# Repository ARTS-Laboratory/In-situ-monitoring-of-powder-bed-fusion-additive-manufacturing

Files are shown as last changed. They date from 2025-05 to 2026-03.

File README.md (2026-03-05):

# In situ monitoring of powder bed fusion additive manufacturing
Hardware and software designs for in situ systems for laser-based powder bed fusion additive manufacturing.

<p align="center">
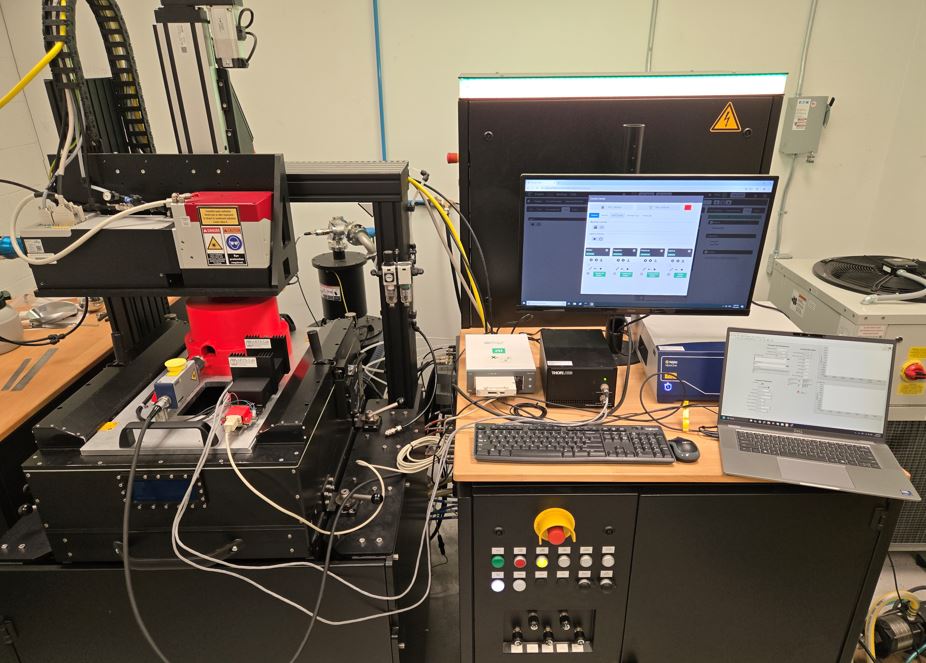
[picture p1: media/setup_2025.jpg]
 <br> 
The laser vibrometer setup of in situ systems for laser-based powder bed fusion additive manufacturing.  
</p>

<p align="center">
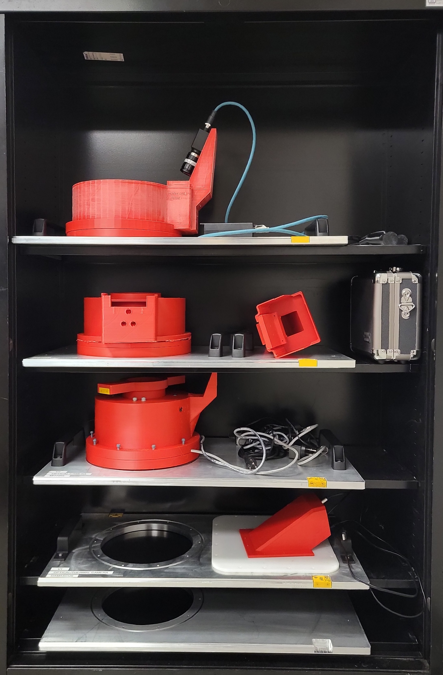
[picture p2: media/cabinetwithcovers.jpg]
 <br> 
Cabinet displaying up to date versions of assembled covers. The following covers in a top-to-bottom arrangement: Uru, Adamant, Mithril, and Damascus. 
</p>

## [System Development](system_development)
The system (hardware and software) design for the project.

## [Aconity MIDI – 3D Reference Models](Aconity_MIDI–3D_Reference_Models)
Simple CAD models for the Aconity MIDI printer used for visualization purposes.

## Licensing and Citation

This work is licensed under a Creative Commons Attribution-ShareAlike 4.0 International License [cc-by-sa 4.0].



#### Bibtex

@Misc{ARTSLabSituMonitoringPowder,  
  author = {{ARTS-L}ab},  
  title  = {In situ monitoring of powder bed fusion additive manufacturing},  
  groups = {{ARTS-L}ab},  
  note = {Accessed: 20xx-xx-xx},  
  url    = {https://github.com/ARTS-Laboratory/In-situ-monitoring-of-Powder-bed-fusion-additive-manufacturing},  
}  

<p align="center">

</p>
<p align="center">
QR code for repo.
</p>

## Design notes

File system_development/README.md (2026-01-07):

# Systems Variations  
Different system variations (i.e., product lines) are named after mythical materials. 

## [Mithril](Mithril)
* A legendary, lightweight, and strong metal from Tolkien’s Middle-earth.
* Sensing system designed with an optical camera.

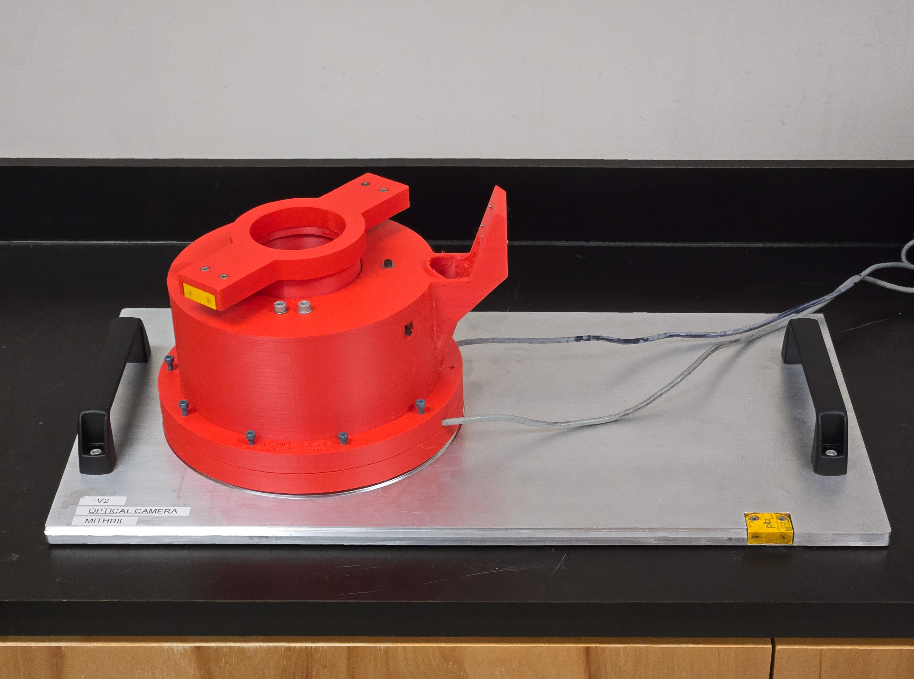
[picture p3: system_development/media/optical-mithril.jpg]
 <br> 
Custom cover with an integrated optical camera mount for laser-based powder bed fusion additive manufacturing monitoring. Camera not yet installed.
</p>

## [Adamant](Adamant)
* An ancient term for an unbreakable, diamond-like substance.
* Sensing system designed with a THERMAL CAMERA.

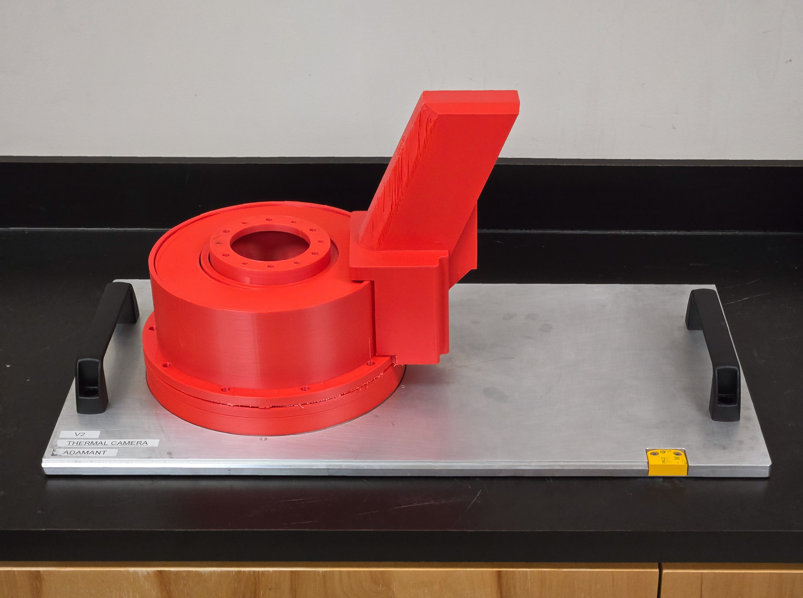
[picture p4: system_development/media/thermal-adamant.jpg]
 <br> 
Custom cover with an integrated thermal camera mount for laser-based powder bed fusion additive manufacturing monitoring. 
</p>

## [Uru](Uru)
* A mystical Asgardian metal, known for its magical properties.
* Sensing system designed with an EVENT CAMERA.

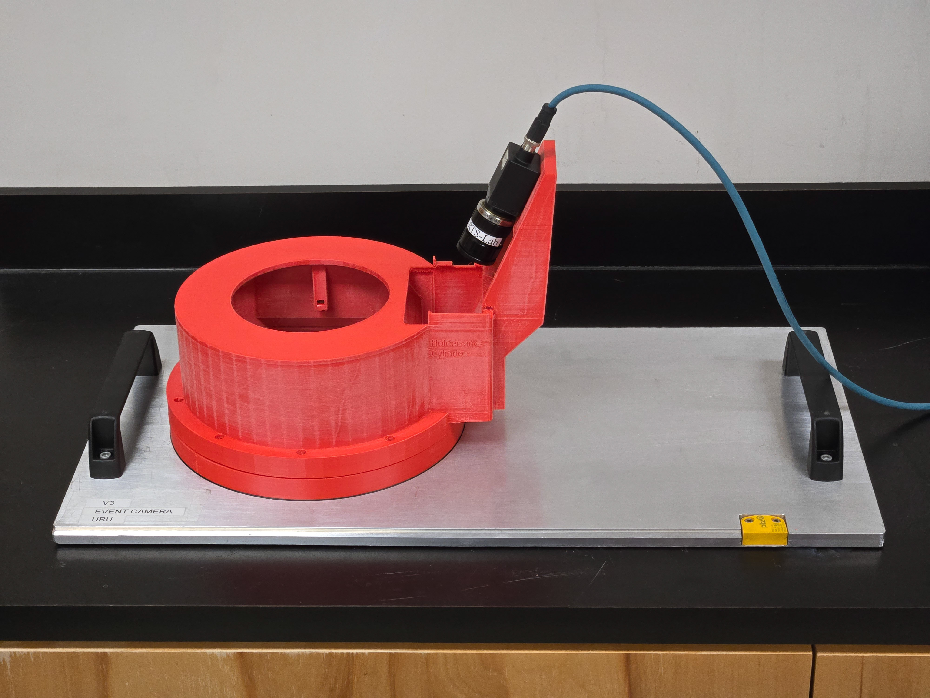
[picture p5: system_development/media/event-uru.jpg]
 <br> 
Custom cover with event camera mount for in-situ monitoring of laser-based powder bed fusion processes.
</p>

## [Orichalcum](Orichalcum)
* A lost golden-red metal from Atlantis and Greek mythology.
* Sensing system designed with a LASER VIBROMETER.

 <br> 
Experimental setup including custom cover assembly, laser vibrometer, piezoelectric transducer, and pulser. 
</p>

## [Damascus](Damascus)
* A famed patterned steel, known for strength and sharpness.
* Sensing system designed with multiple sensing systems.

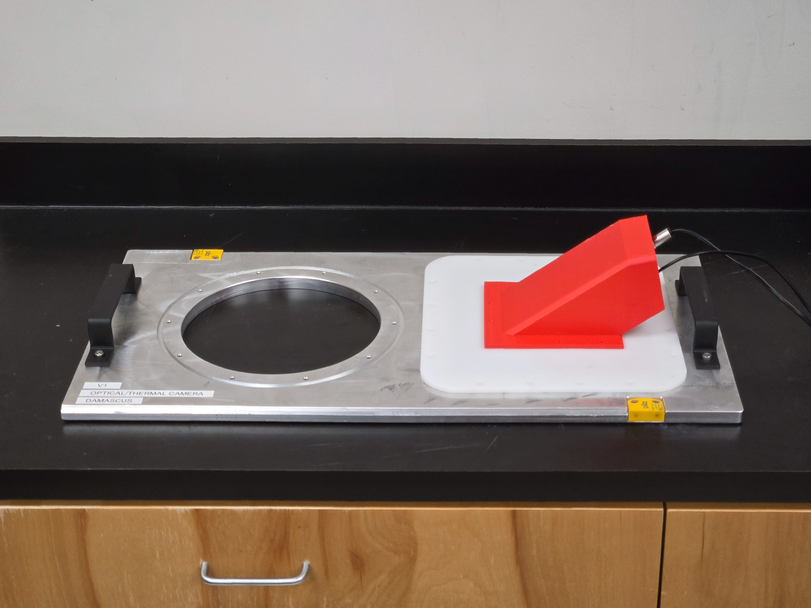
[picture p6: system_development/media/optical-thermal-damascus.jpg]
 <br> 
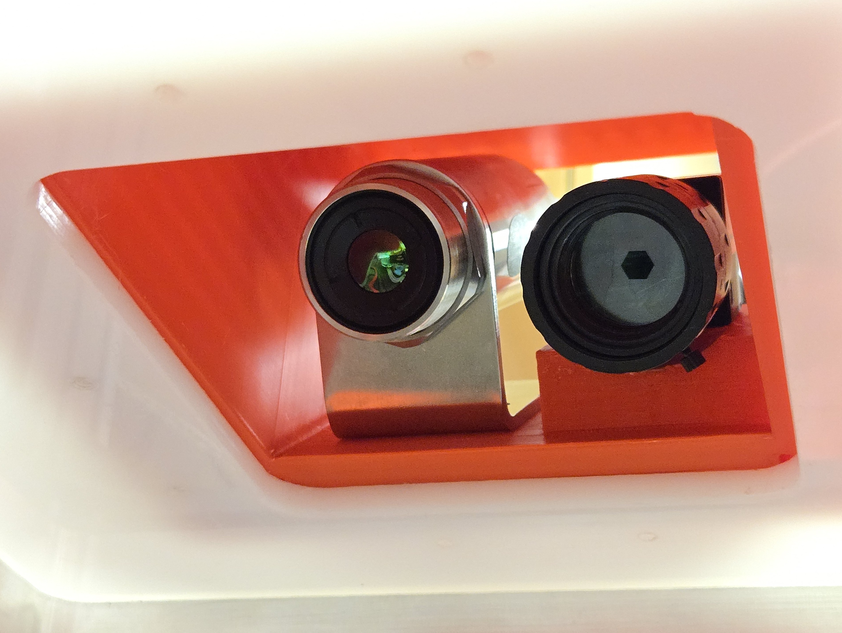
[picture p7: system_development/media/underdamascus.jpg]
 <br> 
Integrated dual vision holder securely mounts a thermal camera and an optical camera for synchronized data acquisition on a custom cover. 
</p>

## [Oblivium](Oblivium)
* A mythical dark metal associated with secrecy, resilience, and hidden power.
* Sensing system designed with EDGE COMPUTING CAPABILITIES for in-situ data processing.
  
 <br> 
 <br> 
Integrated edge computing hardware with an optical camera setup for synchronized data acquisition and processing on a custom cover. 
</p>

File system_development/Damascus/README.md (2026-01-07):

# Damascus
Sensing system designed with multiple sensing systems.

## V0.1
Dual vision holder designed for thermal and optical cameras 
## V0.2
Dual vision holder designed for optical and event cameras 
## V0.3
Triple vision holder desinged for optical, thermal, and event cameras 
To-Do 
    - Expand plate to cover entire hole without spacer
    - Use M6 bolts to mount lid

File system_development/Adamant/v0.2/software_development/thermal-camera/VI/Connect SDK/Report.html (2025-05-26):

Import Shared Library Report

Friday, May 16, 2025 3:06:13 PM

Your generated files are installed in the following folder:
C:\Users\mayhe\OneDrive\Documents\GitHub\In-situ-monitoring-of-powder-bed-fusion-additive-manufacturing\system_development\Orichalcum\v0.2\Software_design\thermal-camera\VI\Connect SDK

Parsing header file warnings:
No errors/warnings occurred when parsing the header file.

The following errors/warnings occurred when generating the wrapper VIs for this shared library.

Cannot create VI
The following VI cannot be created. This might indicate that the associated function contains parameters of a data type that cannot be converted directly. To work around this issue, you can create a custom control or typedef control to represent a complex structure or multidimensional array, then re-run the Import Shared Library wizard and select Update VIs from a shared library. Using the same shared library, step through the wizard again. On the Configure VIs and Controls page, assign the custom control or typedef to the associated parameter(s). Complex structures include nested structures, structures containing arrays, arrays of strings, and multidimensional arrays.
Get Fixed Emissivity.vi
Init Imager IPC.vi
Release Imager IPC.vi
Run Imager IPC.vi
Set Fixed Emissivity.vi
Set Imager IPC Count.vi

VI Not Executable
The VI is not executable because of one of the following reasons:
1. The shared library or a dependent file is not installed. To make the VI executable, you must install the shared library and all support files on the computer on which you run the VI.
2. A required custom control might be empty or cannot be found. To make the VI executable, update the custom control manually.
3. The VI contains a parameter with an unsupported data type. To make the VI executable, you must replace the empty cluster that the wizard generates with a control or indicator that uses supported data types.
Set Callback On Areas Init.vi
Set Callback On Config Changed.vi
Set Callback On Frame Init.vi
Set Callback On Init Completed.vi
Set Callback On LS Slit Center Line.vi
Set Callback On New Frame.vi
Set Callback On New Visible Frame.vi
Set Callback On Play Metadata.vi
Set Callback On Server Stopped.vi
Set Callback On Visible Frame Init.vi

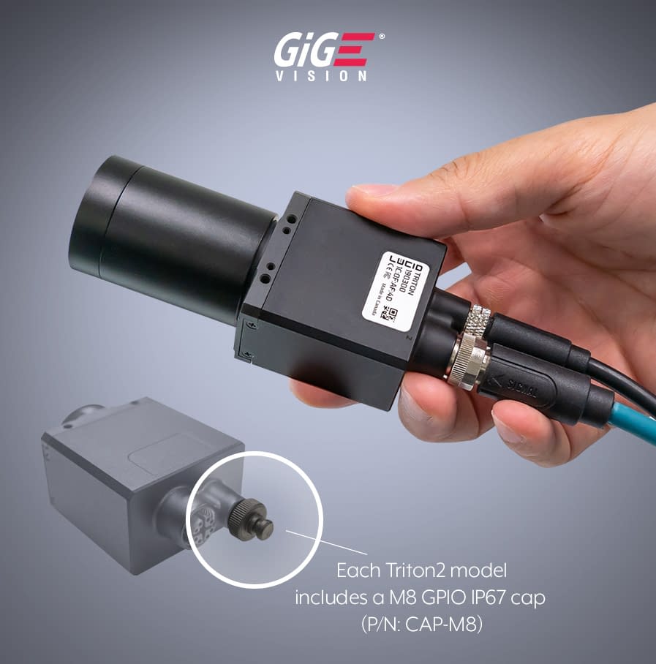
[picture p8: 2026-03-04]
system_development/Uru/Triton2 EVS 0.3MP (IMX637) - EventCamera_files/Triton2-camera-hand-IP67.jpg

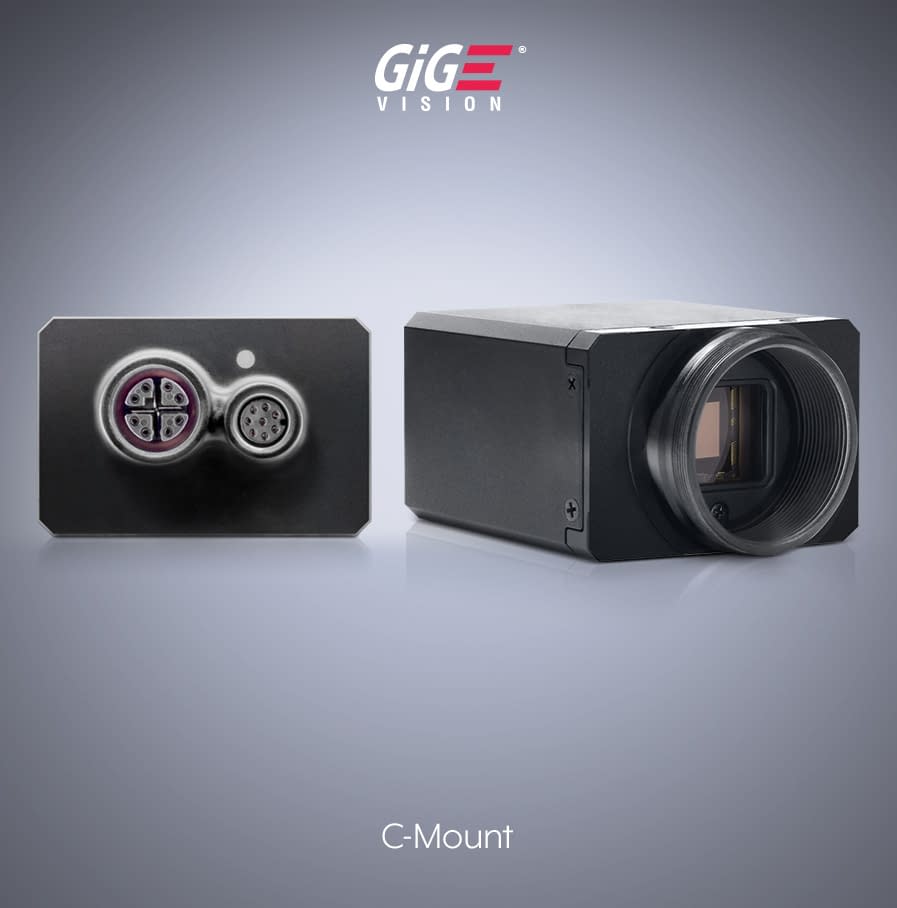
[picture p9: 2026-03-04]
system_development/Uru/Triton2 EVS 0.3MP (IMX637) - EventCamera_files/Triton2-2.5GigE-back-side.jpg

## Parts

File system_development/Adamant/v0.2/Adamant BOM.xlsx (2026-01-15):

Name | Quantity | Source
Aluminum Cover | 1 | Xometry + model
Pull Handle | 2 | https://www.grainger.com/product/JW-WINCO-Pull-Handle-Unthreaded-Holes-813RC8
Horsehoe | 1 | Xometry + model
Head Plate (metal) | 1 | Xometry + model
Welding glass | 1 | Laser Vision (https://lasersafety.com/product/p5p10-window/) | Glass1 (https://www.mscdirect.com/product/details/62674445) | Glass2 (https://www.mscdirect.com/product/details/62674403) | Glass3 (https://www.mscdirect.com/product/details/62674437) | Glass4 (https://www.mscdirect.com/product/details/62674411)
Xi 400 20mm | 1 | optris
Seal Glass Ring | 1 | 3D Printed
Cylinder Housing | 1 | 3D Printed
Camera Lid | 1 | 3D Printed
Cylinder Segment Inner | 1 | 3D Printed
Cylinder Segment Outer | 1 | 3D Printed
Magnet Sensors | 4 | Aconity
M6x15 | 2
M6x20 | 5
M6 ID 11.8mm OD Washer | 7
M6 Nut | 3
M5x40 | 12
M5x20 | 1
M5 ID 9.8mm OD Washer | 16
M5 Nut | 4
M4x14 | 11
M4 ID 8.8mm OD Washer | 11
Rubber Seal (100ft) | 1 | https://www.grainger.com/product/Rubber-Cord-Buna-N-848F88

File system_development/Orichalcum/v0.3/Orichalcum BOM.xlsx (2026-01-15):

Name | Quantity | Source
Aluminum Cover | 1 | Xometry + model
Pull Handle | 2 | https://www.grainger.com/product/JW-WINCO-Pull-Handle-Unthreaded-Holes-813RC8
Head Plate (metal) | 1 | Xometry + model
Seal Glass Ring | 1 | 3D Printed
Cylinder Housing Base | 1 | 3D Printed
Cylinder Housing Cap | 1 | 3D Printed
GV Mount Plate | 1 | 3D Printed
LV Bracket | 1 | 3D Printed
Center Cylinder | 1 | 3D Printed
Magnet Sensors | 4 | Aconity
70mm 8020 Beam | 1
485mm 8020 Beam | 1
M5 x 10 Pan Head | 2
8020 T Nut | 2
M6x20 Set Screw | 2
M6x12 | 2
M6x20 | 4
M6 ID 11.8mm OD Washer | 4
M5x40 | 8
M5x15 | 1
M5 ID 9.8mm OD Washer | 8
M4x14 | 11
M4 ID 8.8mm OD Washer | 11
Rubber Seal (100ft) | 1 | https://www.grainger.com/product/Rubber-Cord-Buna-N-848F88

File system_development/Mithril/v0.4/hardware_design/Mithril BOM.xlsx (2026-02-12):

Name | Quantity | Source
Aluminum Cover | 1 | Xometry + model
Pull Handle | 2 | https://www.grainger.com/product/JW-WINCO-Pull-Handle-Unthreaded-Holes-813RC8
Head Plate (metal) | 1 | Xometry + model
FLIR Blackfly Camera | 1
Edmunds Optis 25mm Lens | 1
Seal Glass Ring | 1 | 3D Printed
Cylinder Housing | 1 | 3D Printed
Camera Lid | 1 | 3D Printed
Cylinder Segment Inner | 1 | 3D Printed
Cylinder Segment Outer | 1 | 3D Printed
Magnet Sensors | 4 | Aconity
M6x15 Bolt | 2
M6x20 Bolt | 4
M6 ID 11.8mm OD Washer | 6
M6 Nut | 2
M5x40 Bolt | 12
M5 ID 9.8mm OD Washer | 15
M4x14 Bolt | 11
M4 ID 8.8mm OD Washer | 11
M3x25 Bolt | 3
M3x10 Pan Head Bolt | 4
M3 Washer | 4
M3 Nuts | 4
Rubber Seal (100ft) | 1 | https://www.grainger.com/product/Rubber-Cord-Buna-N-848F88

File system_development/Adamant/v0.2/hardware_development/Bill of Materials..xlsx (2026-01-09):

Name | Quantity | Source 1 | Source 2 | Source 3
Cover | 1 | Xometry + model
300mm Housing 1 | 1 | 3D Printed
300mm Housing 2 | 1 | 3D Printed
Cylinder Spacer | 1 | 3D Printed
Cylinder Segment Inner | 1 | 3D Printed
Cylinder Segment Outer | 1 | 3D Printed
Cylinder Segment 1 | 1 | 3D Printed
Cylinder Segment Face | 1 | 3D Printed
Camera Bracket | 1 | 3D Printed
Flir Camera Blackfly | 1 | Teledyne Flir Blackfly S USB3 1.6MP Color Camera BFS-U3-16S2C-CS (https://www.bhphotovideo.com/c/product/1844599-REG/teledyne_flir_bfs_u3_16s2c_cs_blackfly_s_usb3_1_6mp.html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)
Welding glass | 1 | Laser Vision (https://lasersafety.com/product/p5p10-window/) | Glass1 (https://www.mscdirect.com/product/details/62674445) | Glass2 (https://www.mscdirect.com/product/details/62674403) | Glass3 (https://www.mscdirect.com/product/details/62674437) | Glass4 (https://www.mscdirect.com/product/details/62674411)
Cover ^ 2 | 1 | 3D Printed
Cover ^ 3 | 1 | 3D Printed
Cylinder Segment Holder | 1 | 3D Printed
Head Plate (metal) | 1 | Xometry + model
M6 x 10 | 4 | M6-1 Thread Size, 10 mm Lg, Socket Head Cap Screw - 26LG36|M07000.060.0010 - Grainger (https://www.grainger.com/product/Socket-Head-Cap-Screw-M6-1-26LG36)
M4 x 14 | 2 | M4-0.7 Thread Size, 14 mm Lg, Socket Head Cap Screw - 4XY51|SC2204014-100P - Grainger (https://www.grainger.com/product/Socket-Head-Cap-Screw-M4-0-4XY51)
M5 x 20 | 10 | https://www.grainger.com/product/Socket-Head-Cap-Screw-M5-0-26LG28
M5 x 50 | 9 | M5-0.8 Thread Size, 50 mm Lg, Socket Head Cap Screw - 6CE82|M07000.050.0050 - Grainger (https://www.grainger.com/product/Socket-Head-Cap-Screw-M5-0-6CE82)
M5 x 16 | 10 | M5-0.8 Thread Size, 16 mm Lg, Socket Head Cap Screw - 23NN83|M51050.050.0016 - Grainger (https://www.grainger.com/product/Socket-Head-Cap-Screw-M5-0-23NN83)
M4 x 12 | 14 | https://www.grainger.com/product/Socket-Head-Cap-Screw-M4-0-22UC39
M3 x 16 | 2 | https://www.grainger.com/product/Socket-Head-Cap-Screw-M3-0-22TZ13
M3 x 8 | 3 | https://www.grainger.com/product/Socket-Head-Cap-Screw-M3-0-22TY48
M3 x 35 | 2 | https://www.grainger.com/product/Socket-Head-Cap-Screw-M3-0-22UC31
M3 x 25 | 1 | https://www.grainger.com/product/Socket-Head-Cap-Screw-M3-0-22UC28
M5 nut | 21 | https://www.grainger.com/product/Hex-Nut-M5-0-80-Thread-22YK31
M3 nut | 3 | https://www.grainger.com/product/Hex-Nut-M3-0-50-Thread-6CA29
M4 nut | 2 | https://www.grainger.com/product/Hex-Nut-M4-0-70-Thread-22UK82
Pull Handle | 2 | https://www.grainger.com/product/JW-WINCO-Pull-Handle-Unthreaded-Holes-813RC8
Rubber Seal | 1 | https://www.grainger.com/product/Buna-N-Round-Cord-Buna-N-6RTT7

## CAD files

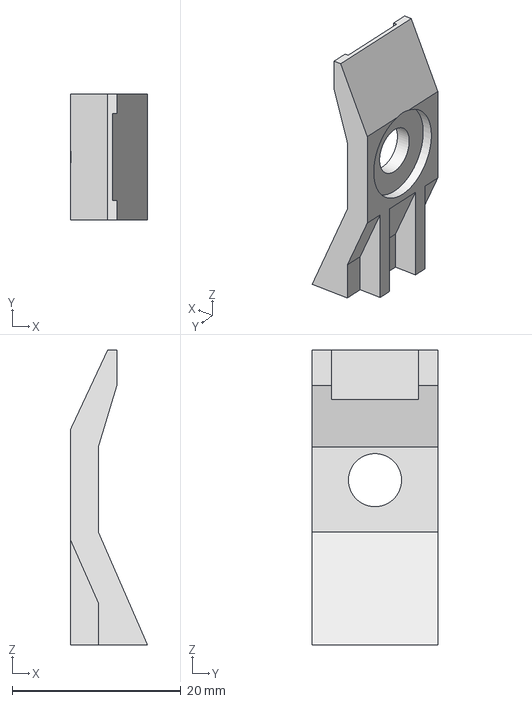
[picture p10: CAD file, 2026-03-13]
accessories/Battery Holder/STEP files/CLAMP.stp
9.15 x 15.0 x 35.0 mm

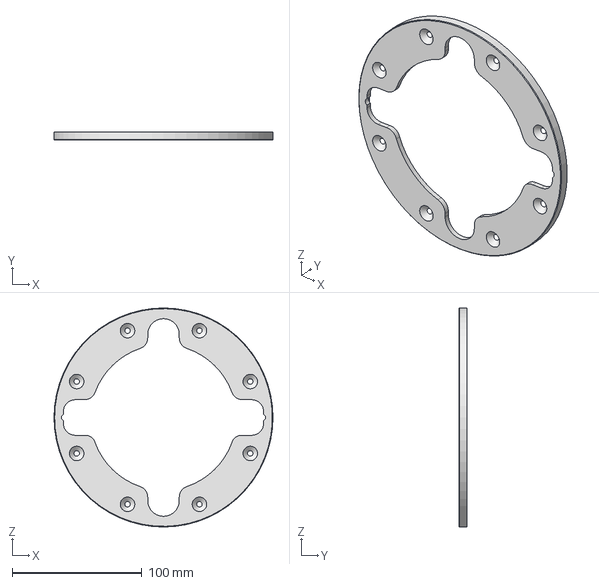
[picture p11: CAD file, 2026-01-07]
accessories/Build platform/Clamp Ring.stp
169.0 x 6.50 x 169.0 mm

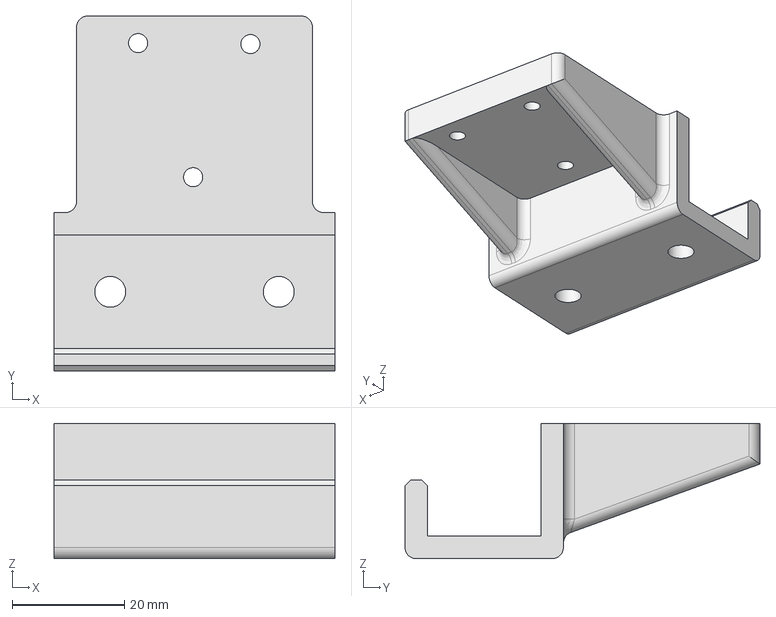
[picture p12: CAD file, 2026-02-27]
accessories/Camera Beam Mount/Optical Camera 8020 Bracket.stp
50.0 x 63.2 x 24.1 mm

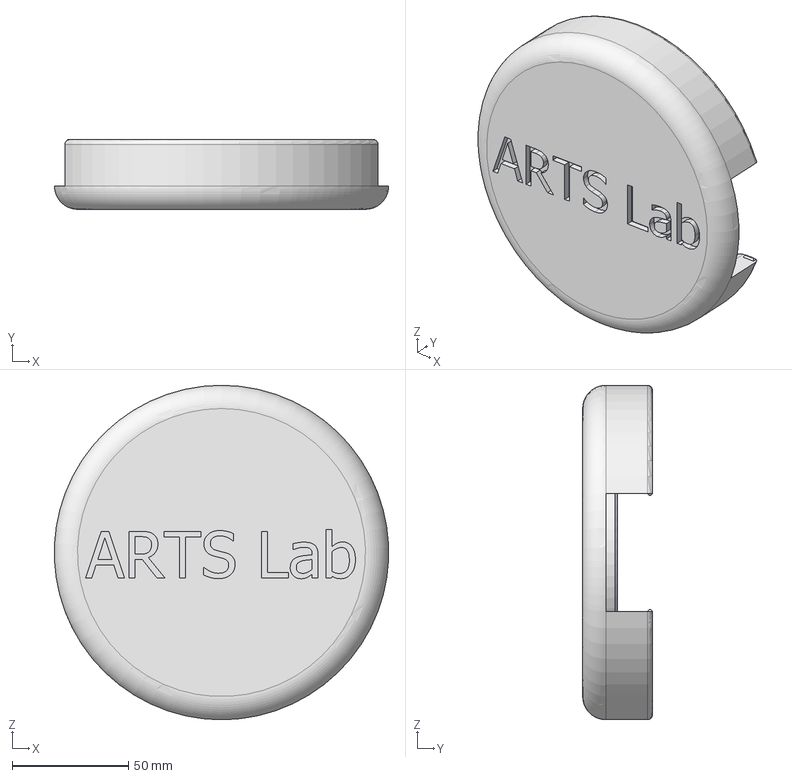
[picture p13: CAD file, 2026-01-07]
accessories/Head plate cover/STEP/Access Cap.stp
143.8 x 30.0 x 144.0 mm

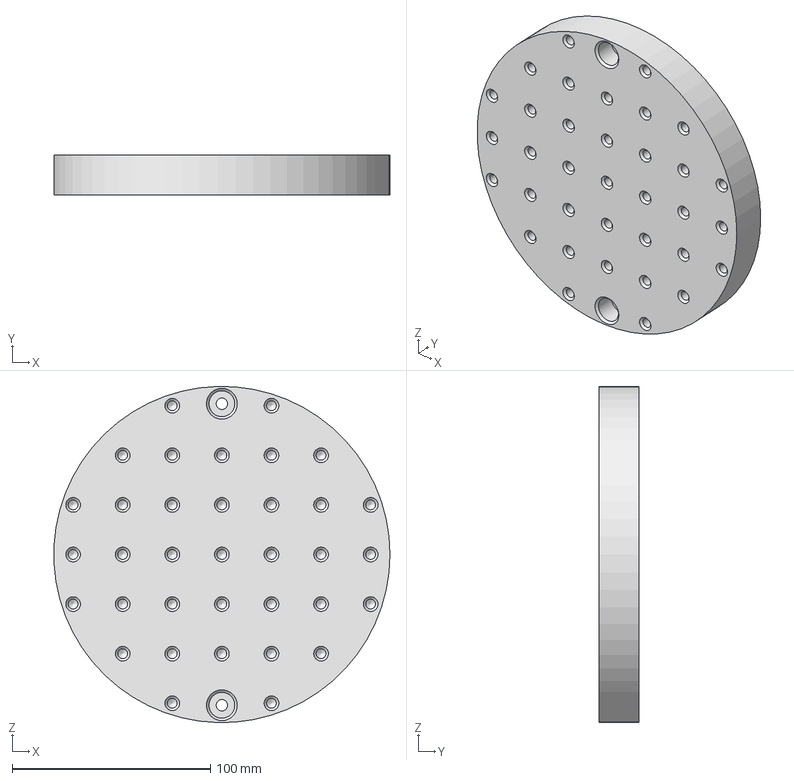
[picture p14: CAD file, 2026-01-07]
accessories/threaded_build-plate/substrate plate With Lots of holes.stp
169.4 x 20.0 x 169.4 mm

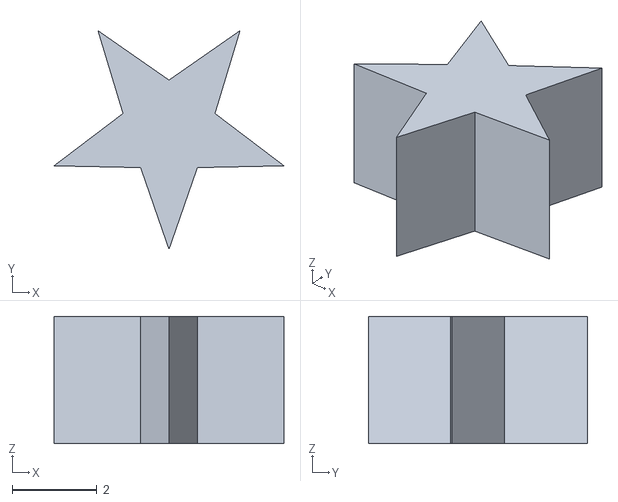
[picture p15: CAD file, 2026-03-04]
system_development/Adamant/v0.2/hardware_development/STEP Files/shape-star-5-points.stl
5.42 x 5.16 x 3.00

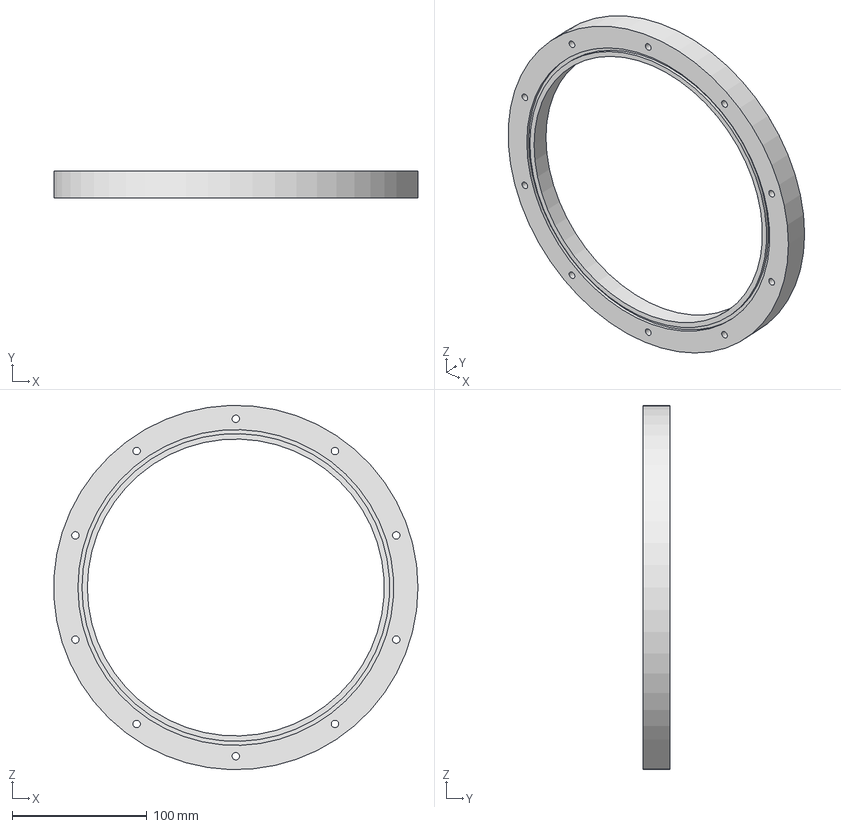
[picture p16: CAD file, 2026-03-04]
system_development/Mithril/v0.4/hardware_design/STEP Files/SealedGlassRing12-16-25.stp
269.7 x 20.0 x 269.9 mm

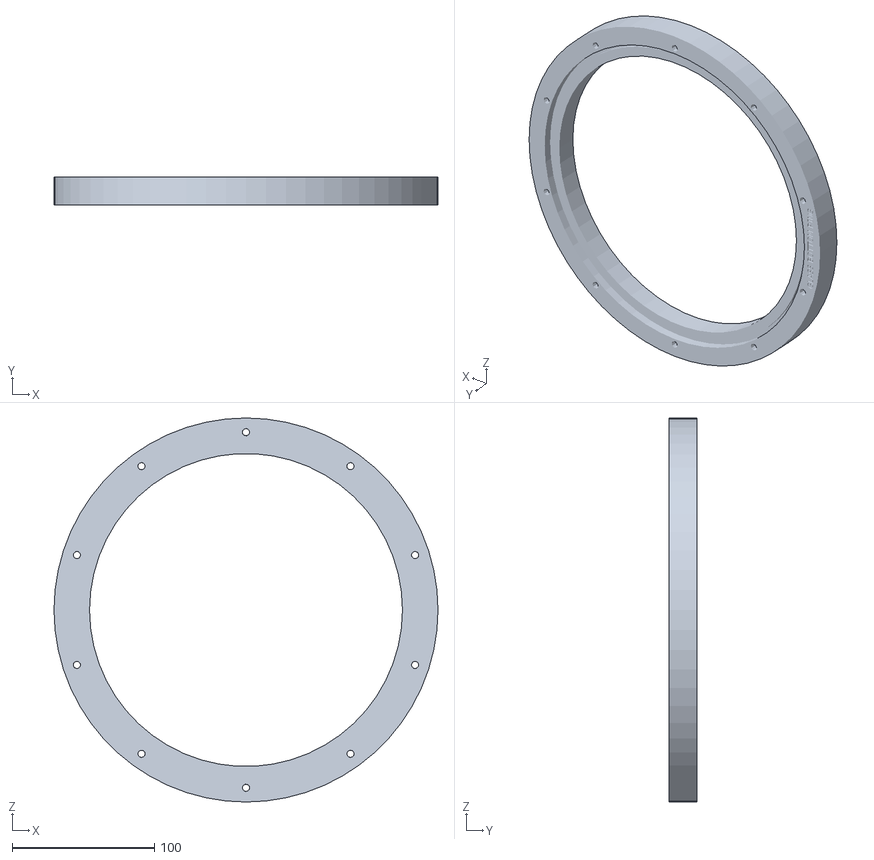
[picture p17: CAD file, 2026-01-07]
system_development/Orichalcum/v0.3/GlassBottomRing.stl
270.0 x 20.0 x 270.0

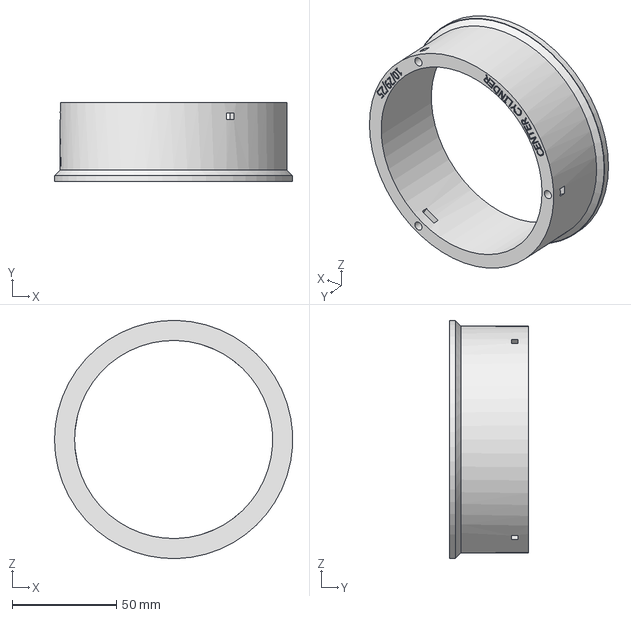
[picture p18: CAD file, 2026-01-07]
system_development/Orichalcum/v0.3/step files/CenterCylinder.stp
114.3 x 38.0 x 114.3 mm

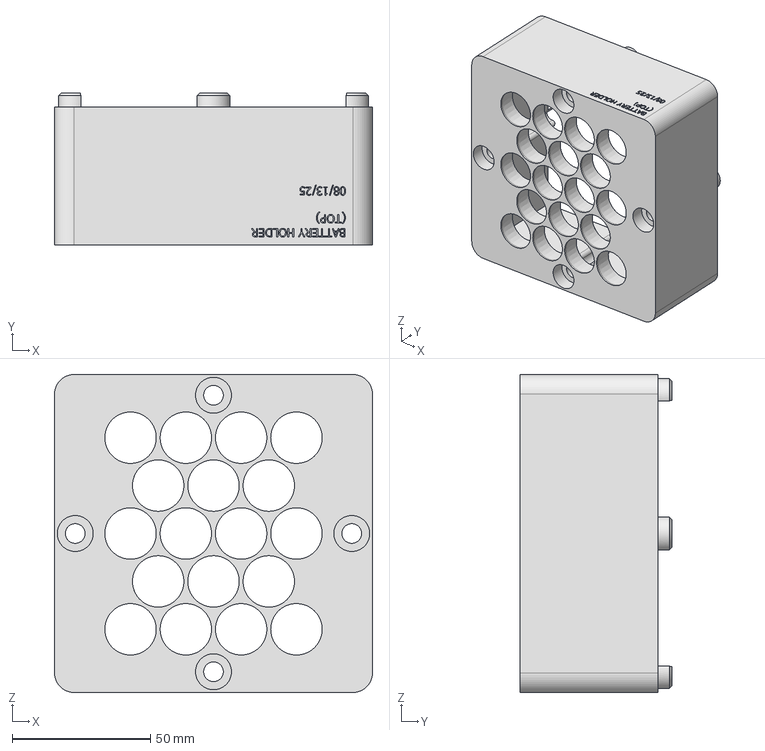
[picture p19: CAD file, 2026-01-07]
accessories/Battery Holder/STEP files/Battery Holder (Top).stp
115.0 x 55.0 x 115.0 mm

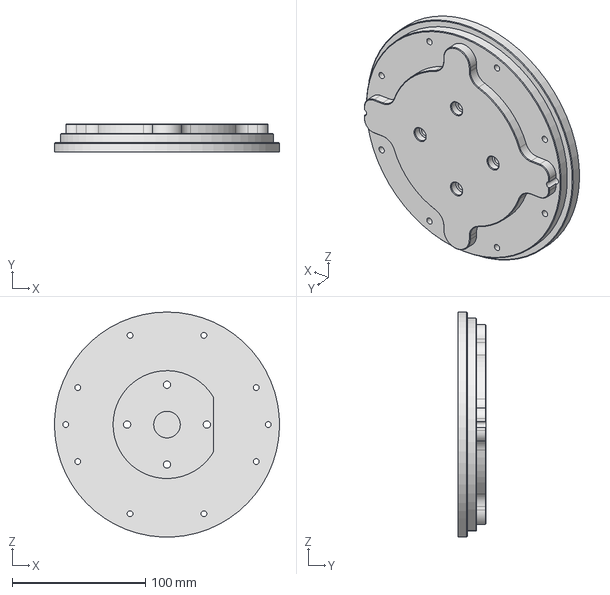
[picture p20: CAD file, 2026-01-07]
accessories/Build platform/Updated Build Platform.stp
168.9 x 21.0 x 168.9 mm

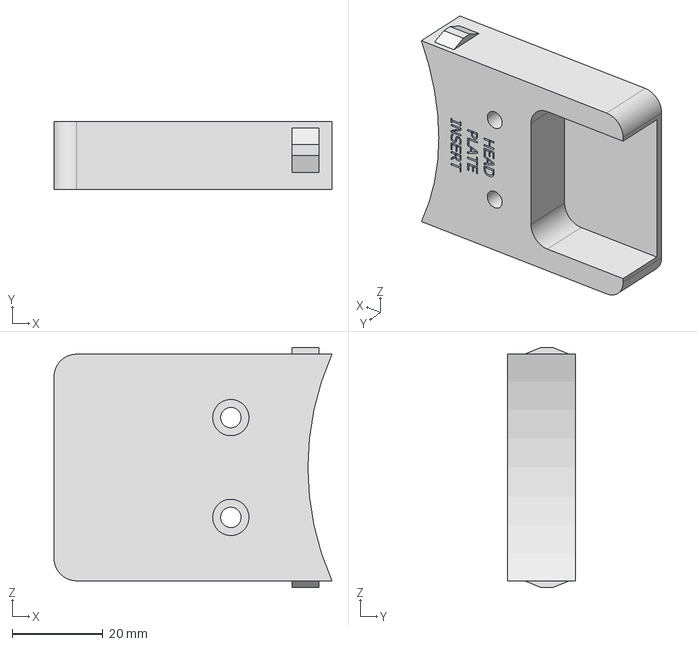
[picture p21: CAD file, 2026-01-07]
accessories/Head plate cover/STEP/Head Plate Insert.stp
61.3 x 15.0 x 53.0 mm

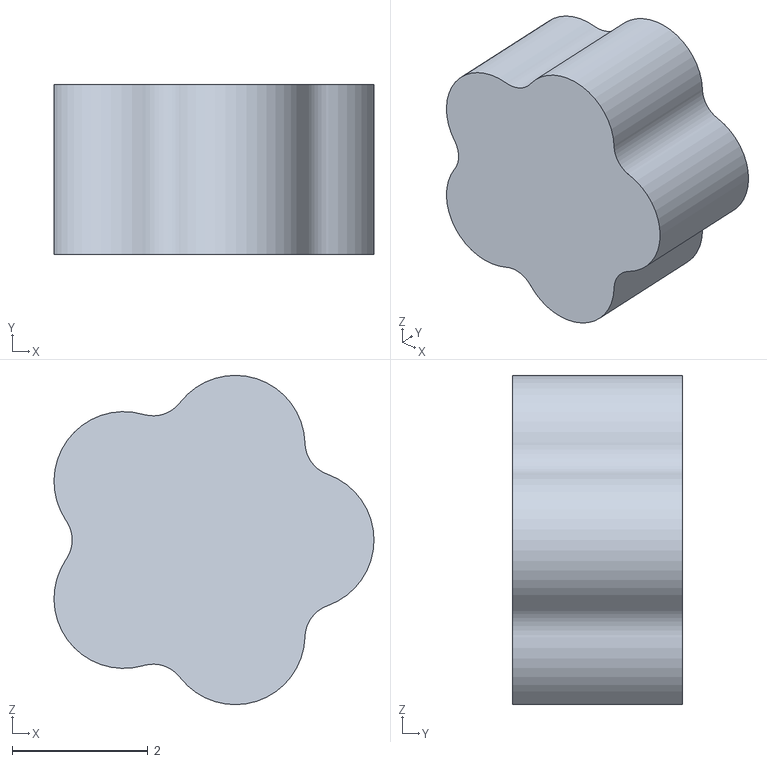
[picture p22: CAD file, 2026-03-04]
system_development/Adamant/v0.2/hardware_development/STEP Files/Flower.stl
4.72 x 2.50 x 4.86

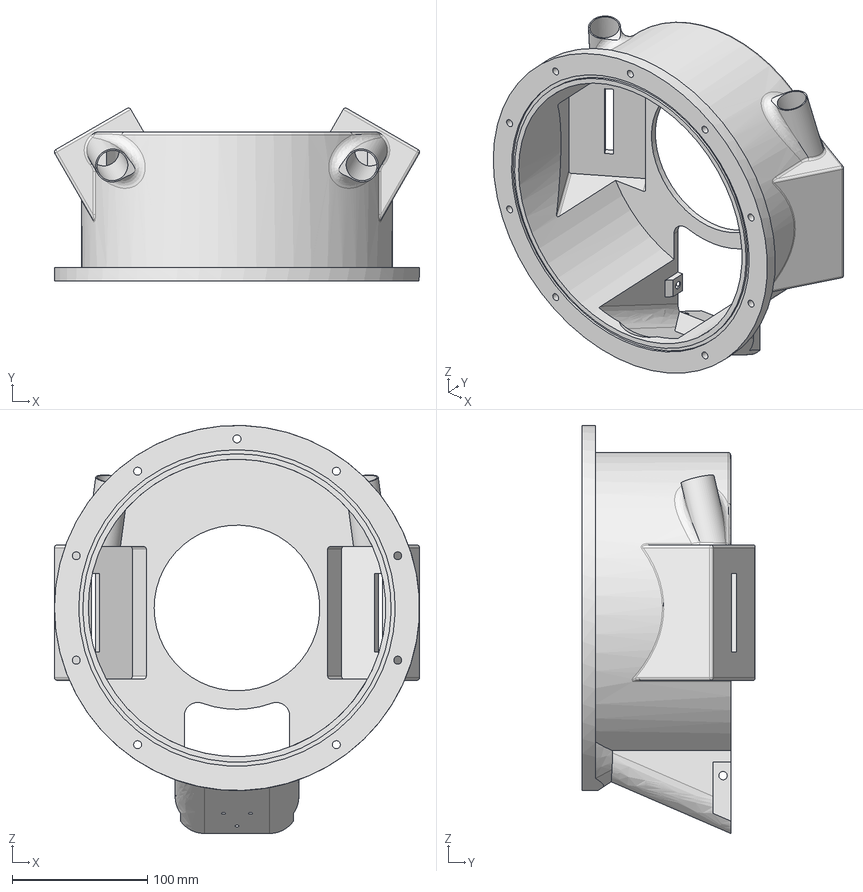
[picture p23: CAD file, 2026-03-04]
system_development/Mithril/v0.4/hardware_design/STEP Files/Optical Housing 2_27_26.stp
270.2 x 127.9 x 301.7 mm

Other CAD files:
system_development/Orichalcum/v0.3/step files/Access Cap.stp
accessories/Battery Holder/STEP files/Battery Holder (Top) 1 Cell.stp
accessories/Head plate cover/STEP/Head Plate Cover Cap.stp
system_development/Adamant/v0.2/hardware_development/STEP Files/shape-circle.stl
Aconity_MIDI-3D_Ref_Models/Printer/Build Plate.ipt
Aconity_MIDI-3D_Ref_Models/Printer/Cover.ipt
Aconity_MIDI-3D_Ref_Models/Printer/Cylinders.ipt
Aconity_MIDI-3D_Ref_Models/Printer/Laser w_ silver v4.iam
Aconity_MIDI-3D_Ref_Models/Printer/OldVersions/Printer Assembly.0007.iam
Aconity_MIDI-3D_Ref_Models/Printer/OldVersions/Printer Cover v10.0002.iam
Aconity_MIDI-3D_Ref_Models/Printer/Printer Assembly.iam
Aconity_MIDI-3D_Ref_Models/Printer/Printer Body v6.ipt
Aconity_MIDI-3D_Ref_Models/Printer/Printer Cover v10.iam
Aconity_MIDI-3D_Ref_Models/Printer/Printer Frame.ipt
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

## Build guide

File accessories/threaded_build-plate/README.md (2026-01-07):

# Threaded build-plate

A threaded build plate for the laser welding system.

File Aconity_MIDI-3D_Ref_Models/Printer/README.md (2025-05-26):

# Aconity MIDI – 3D Reference Models
Assembly of the printer we are working with.

<p align="center">
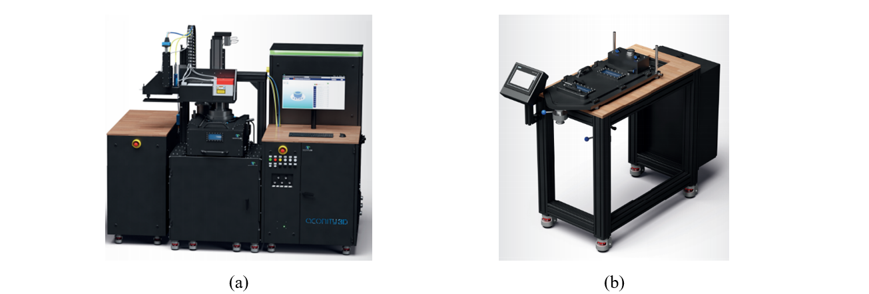
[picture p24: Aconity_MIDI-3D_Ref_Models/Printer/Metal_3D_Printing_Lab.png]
Figure Caption
  
</p>

**Figure 1:** Aconity MIDI Metal 3d printer, showing the: (a) Aconity MIDI, metal LPBFAM printer, and; (b)
sieve station for powder recycling.

## Cover
* The cover or lid for the printer (no cylinder)

## Laser w/ Silver
* Laser platform assembly

## Inner chamber piece
* Piece that adds new powder over the previous layer

## Overhead Laser Unit
* Laser unit, a part of Laser w/ Silver assembly

## Silver 
* Rail that the laser unit rides on

## Cylinders
* Contains the telescoping rings that mate with the laser assembly

## Printer Assembly
* Full printer assembly with all parts

## Printer Body 
* Printer chamber

## Printer Cover
* Cover assembly with Cylinder

## Printer Frame 
* Many parts are attached to the frame

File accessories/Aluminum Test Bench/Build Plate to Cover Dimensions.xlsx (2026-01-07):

Leg | 263.5
Length Beam | 40
Build Plate | 15
Build Platform | 21
Piezo | 16
Adapter Height | 26.5
Cover to Plate | 145

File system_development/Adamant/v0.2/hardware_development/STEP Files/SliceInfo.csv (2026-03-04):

Layer | Layer Height [mm] | Area [mm²] | Contours [mm] | Hatches [mm]
1 | -1.440 | 0.00 | 0.00 | 0.00
2 | -1.425 | 18.07 | 15.08 | 0.00
3 | -1.410 | 18.07 | 15.08 | 0.00
4 | -1.395 | 18.07 | 15.08 | 0.00
5 | -1.380 | 18.07 | 15.08 | 0.00
6 | -1.365 | 18.07 | 15.08 | 0.00
7 | -1.350 | 18.07 | 15.08 | 0.00
8 | -1.335 | 18.07 | 15.08 | 0.00
9 | -1.320 | 18.07 | 15.08 | 0.00
10 | -1.305 | 18.07 | 15.08 | 0.00
11 | -1.290 | 18.07 | 15.08 | 0.00
12 | -1.275 | 18.07 | 15.08 | 0.00
13 | -1.260 | 18.07 | 15.08 | 0.00
14 | -1.245 | 18.07 | 15.08 | 0.00
15 | -1.230 | 18.07 | 15.08 | 0.00
16 | -1.215 | 18.07 | 15.08 | 0.00
17 | -1.200 | 18.07 | 15.08 | 0.00
18 | -1.185 | 18.07 | 15.08 | 0.00
19 | -1.170 | 18.07 | 15.08 | 0.00
20 | -1.155 | 18.07 | 15.08 | 0.00
21 | -1.140 | 18.07 | 15.08 | 0.00
22 | -1.125 | 18.07 | 15.08 | 0.00
23 | -1.110 | 18.07 | 15.08 | 0.00
24 | -1.095 | 18.07 | 15.08 | 0.00
25 | -1.080 | 18.07 | 15.08 | 0.00
26 | -1.065 | 18.07 | 15.08 | 0.00
27 | -1.050 | 18.07 | 15.08 | 0.00
28 | -1.035 | 18.07 | 15.08 | 0.00
29 | -1.020 | 18.07 | 15.08 | 0.00
30 | -1.005 | 18.07 | 15.08 | 0.00
31 | -1.000 | 18.07 | 15.08 | 0.00
32 | -0.990 | 614.87 | 2807.33 | 0.00
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

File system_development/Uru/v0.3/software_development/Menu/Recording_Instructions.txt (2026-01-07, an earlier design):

metavision_viewer.exe 
  -Simple viewer to stream events from an event file or a device, using the SDK driver API.

  Error Fixing
	1. If you are getting errors try manually launching metavision_viewer.exe
	2. Ensure all hardware is plugged in correctly
	3. Ensure that all cords and POI injector can handle stream rate
	4. Adjust settings

Recording Options:
  -Define a region using the cursor (click and drag) to set a Region of Interest (ROI)
  -Press SPACE key while running to record or stop recording raw data
  -Press 'q' or Escape key to leave the program.
  -Press 'o' to toggle the on screen display.
  -Press 'l' to load the camera settings from the input camera config file.
  -Press 's' to save the camera settings to the output camera config file.
  -Press 'r' to toggle the hardware ROI mode (window mode or lines mode, default: window mode).
  -Press 'R' to toggle the ROI/RONI mode.
  -Press 'e' to toggle the ERC module (if available).
  -Press '+' to increase the ERC threshold (if available).
  -Press '-' to decrease the ERC threshold (if available).
  -Press 'h' to print this help.

Input Options:
  -h [ --help ]                         Produce help message.
  -s [ --serial ] arg                   Serial ID of the camera. This flag is
                                        incompatible with flag
                                        '--input-event-file'.
  -i [ --input-event-file ] arg         Path to input event file (RAW, DAT or
                                        HDF5). If not specified, the camera
                                        live stream is used.
  -j [ --input-camera-config ] arg      Path to a JSON file containing camera
                                        config settings to restore a camera
                                        state. Only works for live cameras.
  -b [ --biases ] arg                   Path to a biases file. If not
                                        specified, the camera will be
                                        configured with the default biases.
  -o [ --output-file ] arg (=data.raw)  Path to an output file used for data
                                        recording. Default value is 'data.raw'.
                                        It also works when reading data from a
                                        file.
  --output-camera-config arg (=settings.json)
                                        Path to a JSON file where to save the
                                        camera config settings. Default value
                                        is 'settings.json'. Only works for live
                                        camera.
  -r [ --roi ] arg                      Hardware ROI to set on the sensor in
                                        the format [x y width height].

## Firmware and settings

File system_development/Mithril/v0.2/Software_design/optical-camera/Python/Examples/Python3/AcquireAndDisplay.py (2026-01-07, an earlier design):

# coding=utf-8
# =============================================================================
# Copyright (c) 2001-2023 FLIR Systems, Inc. All Rights Reserved.
#
# This software is the confidential and proprietary information of FLIR
# Integrated Imaging Solutions, Inc. ("Confidential Information"). You
# shall not disclose such Confidential Information and shall use it only in
# accordance with the terms of the license agreement you entered into
# with FLIR Integrated Imaging Solutions, Inc. (FLIR).
#
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
# This AcquireAndDisplay.py shows how to get the image data, and then display images in a GUI.
# This example relies on information provided in the ImageChannelStatistics.py example.
#
# This example demonstrates how to display images represented as numpy arrays.
# Currently, this program is limited to single camera use.
# NOTE: keyboard and matplotlib must be installed on Python interpreter prior to running this example.
#
# Please leave us feedback at: https://www.surveymonkey.com/r/TDYMVAPI
# More source code examples at: https://github.com/Teledyne-MV/Spinnaker-Examples
# Need help? Check out our forum at: https://teledynevisionsolutions.zendesk.com/hc/en-us/community/topics


import os
import PySpin
import matplotlib.pyplot as plt
import sys
import keyboard
import time

global continue_recording
continue_recording = True


def handle_close(evt):
    """
    This function will close the GUI when close event happens.

    :param evt: Event that occurs when the figure closes.
    :type evt: Event
    """

    global continue_recording
    continue_recording = False


def acquire_and_display_images(cam, nodemap, nodemap_tldevice):
    """
    This function continuously acquires images from a device and display them in a GUI.

    :param cam: Camera to acquire images from.
    :param nodemap: Device nodemap.
    :param nodemap_tldevice: Transport layer device nodemap.
    :type cam: CameraPtr
    :type nodemap: INodeMap
    :type nodemap_tldevice: INodeMap
    :return: True if successful, False otherwise.
    :rtype: bool
    """
    global continue_recording

    sNodemap = cam.GetTLStreamNodeMap()

    # Change bufferhandling mode to NewestOnly
    node_bufferhandling_mode = PySpin.CEnumerationPtr(sNodemap.GetNode('StreamBufferHandlingMode'))
    if not PySpin.IsReadable(node_bufferhandling_mode) or not PySpin.IsWritable(node_bufferhandling_mode):
        print('Unable to set stream buffer handling mode.. Aborting...')
        return False

    # Retrieve entry node from enumeration node
    node_newestonly = node_bufferhandling_mode.GetEntryByName('NewestOnly')
    if not PySpin.IsReadable(node_newestonly):
        print('Unable to set stream buffer handling mode.. Aborting...')
        return False

    # Retrieve integer value from entry node
    node_newestonly_mode = node_newestonly.GetValue()

    # Set integer value from entry node as new value of enumeration node
    node_bufferhandling_mode.SetIntValue(node_newestonly_mode)

    print('*** IMAGE ACQUISITION ***\n')
    try:
        node_acquisition_mode = PySpin.CEnumerationPtr(nodemap.GetNode('AcquisitionMode'))
        if not PySpin.IsReadable(node_acquisition_mode) or not PySpin.IsWritable(node_acquisition_mode):
            print('Unable to set acquisition mode to continuous (enum retrieval). Aborting...')
            return False

        # Retrieve entry node from enumeration node
        node_acquisition_mode_continuous = node_acquisition_mode.GetEntryByName('Continuous')
        if not PySpin.IsReadable(node_acquisition_mode_continuous):
            print('Unable to set acquisition mode to continuous (entry retrieval). Aborting...')
            return False

        # Retrieve integer value from entry node
        acquisition_mode_continuous = node_acquisition_mode_continuous.GetValue()

        # Set integer value from entry node as new value of enumeration node
        node_acquisition_mode.SetIntValue(acquisition_mode_continuous)

        print('Acquisition mode set to continuous...')

        #  Begin acquiring images
        #
        #  *** NOTES ***
        #  What happens when the camera begins acquiring images depends on the
        #  acquisition mode. Single frame captures only a single image, multi
        #  frame catures a set number of images, and continuous captures a
        #  continuous stream of images.
        #
        #  *** LATER ***
        #  Image acquisition must be ended when no more images are needed.
        cam.BeginAcquisition()

        print('Acquiring images...')

        #  Retrieve device serial number for filename
        #
        #  *** NOTES ***
        #  The device serial number is retrieved in order to keep cameras from
        #  overwriting one another. Grabbing image IDs could also accomplish
        #  this.
        device_serial_number = ''
        node_device_serial_number = PySpin.CStringPtr(nodemap_tldevice.GetNode('DeviceSerialNumber'))
        if PySpin.IsReadable(node_device_serial_number):
            device_serial_number = node_device_serial_number.GetValue()
            print('Device serial number retrieved as %s...' % device_serial_number)

        # Close program
        print('Press enter to close the program..')

        # Figure(1) is default so you can omit this line. Figure(0) will create a new window every time program hits this line
        fig = plt.figure(1)

        # Close the GUI when close event happens
        fig.canvas.mpl_connect('close_event', handle_close)

        # Retrieve and display images
        while(continue_recording):
            try:

                #  Retrieve next received image
                #
                #  *** NOTES ***
                #  Capturing an image houses images on the camera buffer. Trying
                #  to capture an image that does not exist will hang the camera.
                #
                #  *** LATER ***
                #  Once an image from the buffer is saved and/or no longer
                #  needed, the image must be released in order to keep the
                #  buffer from filling up.
                
                image_result = cam.GetNextImage(1000)

                #  Ensure image completion
                if image_result.IsIncomplete():
                    print('Image incomplete with image status %d ...' % image_result.GetImageStatus())

                else:                    

                    # Getting the image data as a numpy array
                    image_data = image_result.GetNDArray()

                    # Draws an image on the current figure
                    plt.imshow(image_data, cmap='gray')

                    # Interval in plt.pause(interval) determines how fast the images are displayed in a GUI
                    # Interval is in seconds.
                    plt.pause(0.001)

                    # Clear current reference of a figure. This will improve display speed significantly
                    plt.clf()
                    
                    # If user presses enter, close the program
                    if keyboard.is_pressed('ENTER'):
                        print('Program is closing...')
                        
                        # Close figure
                        plt.close('all')             
                        input('Done! Press Enter to exit...')
                        continue_recording=False                        

                #  Release image
                #
                #  *** NOTES ***
                #  Images retrieved directly from the camera (i.e. non-converted
                #  images) need to be released in order to keep from filling the
                #  buffer.
                image_result.Release()

            except PySpin.SpinnakerException as ex:
                print('Error: %s' % ex)
                return False

        #  End acquisition
        #
        #  *** NOTES ***
        #  Ending acquisition appropriately helps ensure that devices clean up
        #  properly and do not need to be power-cycled to maintain integrity.
        cam.EndAcquisition()

    except PySpin.SpinnakerException as ex:
        print('Error: %s' % ex)
        return False

    return True


def run_single_camera(cam):
    """
    This function acts as the body of the example; please see NodeMapInfo example
    for more in-depth comments on setting up cameras.

    :param cam: Camera to run on.
    :type cam: CameraPtr
    :return: True if successful, False otherwise.
    :rtype: bool
    """
    try:
        result = True

        nodemap_tldevice = cam.GetTLDeviceNodeMap()

        # Initialize camera
        cam.Init()

        # Retrieve GenICam nodemap
        nodemap = cam.GetNodeMap()

        # Acquire images
        result &= acquire_and_display_images(cam, nodemap, nodemap_tldevice)

        # Deinitialize camera
        cam.DeInit()

    except PySpin.SpinnakerException as ex:
        print('Error: %s' % ex)
        result = False

    return result


def main():
    """
    Example entry point; notice the volume of data that the logging event handler
    prints out on debug despite the fact that very little really happens in this
    example. Because of this, it may be better to have the logger set to lower
    level in order to provide a more concise, focused log.

    :return: True if successful, False otherwise.
    :rtype: bool
    """
    result = True

    # Retrieve singleton reference to system object
    system = PySpin.System.GetInstance()

    # Get current library version
    version = system.GetLibraryVersion()
    print('Library version: %d.%d.%d.%d' % (version.major, version.minor, version.type, version.build))

    # Retrieve list of cameras from the system
    cam_list = system.GetCameras()

    num_cameras = cam_list.GetSize()

    print('Number of cameras detected: %d' % num_cameras)

    # Finish if there are no cameras
    if num_cameras == 0:

        # Clear camera list before releasing system
        cam_list.Clear()

        # Release system instance
        system.ReleaseInstance()

        print('Not enough cameras!')
        input('Done! Press Enter to exit...')
        return False

    # Run example on each camera
    for i, cam in enumerate(cam_list):

        print('Running example for camera %d...' % i)

        result &= run_single_camera(cam)
        print('Camera %d example complete... \n' % i)

    # Release reference to camera
    # NOTE: Unlike the C++ examples, we cannot rely on pointer objects being automatically
    # cleaned up when going out of scope.
    # The usage of del is preferred to assigning the variable to None.
    del cam

    # Clear camera list before releasing system
    cam_list.Clear()

    # Release system instance
    system.ReleaseInstance()

    input('Done! Press Enter to exit...')
    return result


if __name__ == '__main__':
    if main():
        sys.exit(0)
    else:
        sys.exit(1)

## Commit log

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2025-05-09 Update C .Replace - 04 v2.0.3mf
    [C .Replace - 04 v2.0.3mf]
2025-05-09 v0.2 & v0.3
    v0.3 is only event camera.
    v0.2 is both optical and event, but isn't done yet.
    [090869.ipt, 090870.ipt, 090879-XX_090879-04.ipt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]
2025-05-15 CAD for new LDV cover
    [Component1.ipt, Cylinder 80-20 Spacer_for New LV v3.ipt, M5x0.iam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]
2025-05-23 Added new way to access info for thermal camera
    [8020-20-.ipt, 8020-20-2020 X 360 MM.step, 8020-20-2020 X 690 MM.step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]
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2025-05-30 Added spreadsheet telling us what lights we have in stock
    [C .Replace - 08.3mf]
2025-05-30 GVS, LDV, & Build Platform Mounts
    [Platform Frame Mount Adapter.0004.ipt, Platform Frame Mount Adapter.0005.ipt, Platform Frame Mount Adapter.ipt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]
2025-06-01 New parts for LV cover
    [Body1.stl, Cylinder 80-20 Spacer_2 cable hole v1.step, Cylinder 80-20 Spacer_for New LV v3.step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]
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2025-06-04 STLs & Aconity Manual
    [D9-housing-bottom.0002.ipt, D9-housing-bottom.ipt, D9-housing-bottom.stl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]
2025-06-07 Create the big cover v1.ipt
    [the big cover v1.ipt]
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2025-06-13 New thermal camera code plus new cover design
    [Cover (Vibrometer).0014.ipt, Cover (Vibrometer).ipt, Handles.ipt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]
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2025-06-25 Added Event Camera Setup
    [090869.ipt, 090870.ipt, 090879-XX_090879-04.ipt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]
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2025-07-08 Delete system_development/Mithril/v0.2/Hardware_design/Cylinder Segment/Cylinder Slidey Bit Housings/OldVersions/Cylinder Slidey Bit Housing Camera only v0.2.0077.ipt
    This file name was too long and had to be eliminated (sad) :(
    [Cylinder Slidey Bit Housing Camera only v0.2.0077.ipt]
2025-07-08 Model containing the first cover
    [091052 (116 126).0001.iam, 091052 (116 126).iam, AL11604 (SEALED).0004.iam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]
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2025-07-17 Dual vision holder v2
    [Coverwithcameraholder.0003.iam, Coverwithcameraholder.iam, Reducer Plate.ipt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]
2025-07-18 Revert "cameraholder"
    This reverts commit dbf4e2750bf1ee0e41a93b6b864ef386daa78444.
    [Cover Optical Camera Only.0045.iam, Cover Optical Camera Only.0047.iam, Cover Optical Camera Only.0048.iam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]
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2025-07-18 File organization and image addition
    [Assembly1.iam, Coverwithcameraholder.0003.iam, Coverwithcameraholder.iam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]
2025-07-24 Dual vision holder updates
    [Assembly1.0002.iam, Assembly1.iam, Camera Bracket.ipt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]
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2025-07-29 Moved thermal image files to the adamant file
    [12mm Aluminum Cover.ipt, Bill of Materials..xlsx, C .Replace - 04 no rib.3mf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]
2025-07-29 Fixed thermal camera assembly model
    [Thermal cover assembly.0001.ipn, Thermal cover assembly.0004.iam, Thermal cover assembly.0005.iam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]
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2025-08-04 dual vision v0.4 and thermal lid v0.2 added
    [AssemblyV0.3.0002.iam, AssemblyV0.3.0004.iam, AssemblyV0.3.iam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]
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2025-08-05 Moved threaded hole plate
    [Optical Breadboard for Ender.ipt, substrate plate With Lots of holes Chamfer.stp, substrate plate With Lots of holes no chamfer.stp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]
2025-08-06 Parts In All Folders
    [12mm Aluminum Cover.ipt, 12mm Cover.0004.ipt, 12mm Cover.0008.ipt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]
2025-08-06 Updated Parts for Newest Versions
    [090869.ipt, 090870.ipt, 090879-XX_090879-04.ipt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]
2025-08-06 Delete system_development/Uru/v0.3/hardware_development/ASM/Cylinder Segment/Cylinder Slidey Bit Housings/OldVersions/Cylinder Slidey Bit Housing Camera only v0.2.0083.ipt
    Exterminated file because name was too long
    [Cylinder Slidey Bit Housing Camera only v0.2.0083.ipt]
2025-08-06 Update Damascus and Adamant folders
    [300mm Housing 1.ipt, C .Replace - Face.ipt, Cylinder Segment Camera Only.0001.ipt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]
2025-08-06 Add my local files
    [090869.ipt, 090870.ipt, 090879-XX_090879-04.ipt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]
2025-08-06 Made Thermal Camera Assembly
    [300mm Housing 1.ipt, C .Replace - Face.ipt, Cylinder Segment Camera Only.ipt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]
2025-08-08 Worked on battery holder for welding
    [Battery Holder.0001.ipt, Battery Holder.ipt, Battery holder assembly.0001.iam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]
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2025-08-13 Battery Holder for welding
    [18650(PINK).ipt, Battery Holder (Bottom).0007.ipt, Battery Holder (Bottom).ipt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]
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2025-08-27 Dual Vision and Thermal Cam Updates
    [Assemblywithlid.0001.iam, Assemblywithlid.iam, C .Replace - 10.ipt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]
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2025-09-04 File Organization and To Do List under Read Me
    [Assembly v0.2.iam, Assembly1.0002.iam, AssemblyV0.3.0004.iam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]
2025-09-04 Fixed Plate with many holes
    [12mm Cover.ipt, Battery Holder (Bottom) 1 Cell.0011.ipt, Battery Holder (Bottom) 1 Cell.ipt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]
2025-09-04 File Organization in Damascus
    [Glass holder.stp, cameraholderbody v0.5.stp]
2025-09-05 Changed name of threaded plate file
    [substrate plate With Lots of holes.stp]
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2025-09-23 Thermal Camera Cover Updates
    [Cylinder Housing Camera v0.2.11.0013.ipt, Cylinder Housing Camera v0.2.11.ipt, Cylinder Housing Camera v0.2.11.stp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]
2025-09-26 Edit to Glass Ring and Thermal Cover
    [Cylinder Housing Camera v0.2.11.0013.ipt, Cylinder Housing Camera v0.2.11.0014.ipt, Cylinder Housing Camera v0.2.11.ipt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]
2025-09-29 New Event camera holder
    Changed it to match the other holders we're using
    [ASM_Testing.0001.iam, ASM_Testing.iam, Cylinder Housing Camera v0.2.11.0015.ipt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]
2025-09-30 optical camera cover v0.3
    [Assembly.0002.iam, Assembly.iam, Cylinder Housing Camera v0.2.11.stp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]
2025-09-30 Moved build platform to the accessories file
    [Build Plateform one Indents (metal).0017.ipt, Build Plateform one Indents (metal).ipt, Build Plateform one Indents (metal).stp]
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2025-10-06 Glass seat update for Optical and Thermal Cam
    [Assembly.0002.iam, Assembly.0004.iam, Assembly.iam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]
2025-10-14 fixed model and updated clamp plate
    [Build Plateform one Indents (metal).ipt, Build Plateform one Indents (metal).stp, Build Platform Assembly.0002.iam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]
2025-10-16 Fixed clamping plate
    [Build Platform Assembly.0002.iam, Build Platform Assembly.0003.iam, Build Platform Assembly.iam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]
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2025-12-30 New Thermal Lid
    lip covers camera opening, simpler model
    [Thermal Lid.0002.ipt, Thermal Lid.0003.ipt, Thermal Lid.ipt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]
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2026-01-17 Changes
    Optical camera housing changes on bottom of housing and new assembly with Uru cover, build plate, and event camera.
    [Assembly of Uru Full Cover.iam, Event Housing.ipt, event camera housing.ipt]
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2026-02-06 Camera mount hole diameter change
    From 220 mm to 124.731 mm
    [12mm Uru Cover.0010.ipt, 12mm Uru Cover.ipt]
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2026-03-01 Mithril Cover 2-27-26
    camera & lens model
    angle correction
    antireflective glass
    [35mmLens.ipt, Antireflective Glass.ipt, Camera Cylinder Housing - Red Lights.ipt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]
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2026-03-02 Mithril Assembly Updates
    material and color selection for nice pictures
    [35mmLens.0004.ipt, 35mmLens.0005.ipt, 35mmLens.ipt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]
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
